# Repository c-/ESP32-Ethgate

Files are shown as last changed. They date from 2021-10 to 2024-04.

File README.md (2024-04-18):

# ESP32-Ethgate

This is an ESP32 (ESP32-WROOM-32 module) with LAN8720A PHY project
intended to be an ESP-NOW to (wired) MQTT gateway.

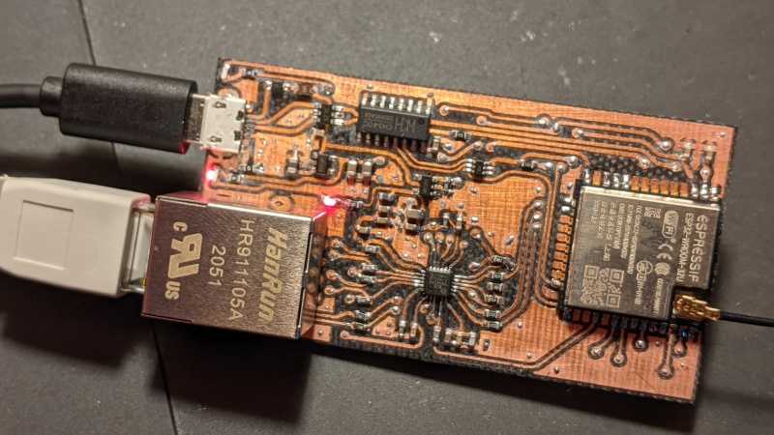
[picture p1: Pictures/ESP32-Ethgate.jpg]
Photo of working board


It was designed to be produced in my PCB mill. If your PCB mill can handle
QFN24 footprints and double-sided PCB's then you might be able to duplicate
this. Or you can just order a PCB from pretty much anywhere.
[I had a few made by Oshpark](https://oshpark.com/shared_projects/cBIYloft).

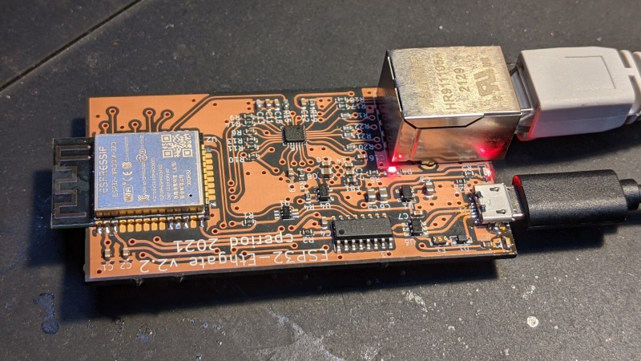
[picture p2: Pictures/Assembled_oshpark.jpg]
Oshpark After Dark PCB


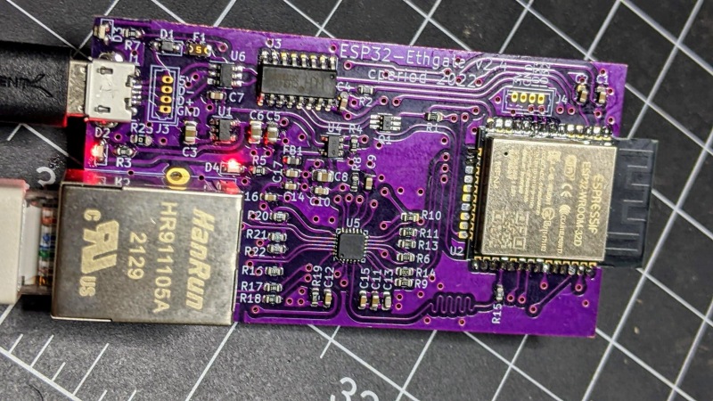
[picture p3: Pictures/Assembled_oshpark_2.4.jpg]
Oshpark After Dark PCB


# Design

For simplicity, it uses the GPIO17 PLL clock technique rather than
the GPIO0-based crystal, and includes a second 3.3v regulator to control
the entire ethernet power rail independently. It needs stable USB power,
although at some point I might take a stab at a PoE version.

The CH340C runs off the first regulator along with the ESP32. The HT7233 is
rated for 300mA, which is just marginal for an ESP32, but so far I haven't
noticed any power issues (power consumption for the whole board averages
maybe 250mA). I've thrown in some USB ESD protection, a fuse,
and some reverse protection (I know that's not supposed to be a problem
with USB... things happen, don't ask). ESD protection for the Ethernet
port would be a nice-to-have at some point.

The CH340C supports the usual auto-programming. Note that you *may* 
need to dial back the default upload baud rate.

I've added a small (1.25mm pitch) header with 3V3, GND, and two GPIO's
to allow for things like environmental sensors. Note that temperature
sensors will need to stay a minimum of 10cm off the board to avoid the heat
thrown by this board. I've also broken out the USB interface with a small
header (uUSB connectors can be brittle pieces of junk).

# BOM

Most of the components are from LCSC. There's an interactive BOM page
which should tell you what you need. Passives are 0603 with a few
0805 for the larger capacitors.

# Firmware

The Arduino-ESP32 ETH_LAN8720 sketch should work with the following
configuration:

```
#define LED_BUILTIN 2	// or use a NodeMCU-type of board definition
#define ETH_CLK_MODE    ETH_CLOCK_GPIO17_OUT
#define ETH_POWER_PIN   12
#define ETH_TYPE        ETH_PHY_LAN8720
#define ETH_ADDR        1
#define ETH_MDC_PIN     23
#define ETH_MDIO_PIN    18

ETH.begin(ETH_ADDR, ETH_POWER_PIN, ETH_MDC_PIN, ETH_MDIO_PIN,
	ETH_TYPE, ETH_CLK_MODE)
```

I flash mine with the ESP32 clock set at 80MHz, which seems to be
more stable at 100Mbps connection speeds and draws approximately 25%
less power.

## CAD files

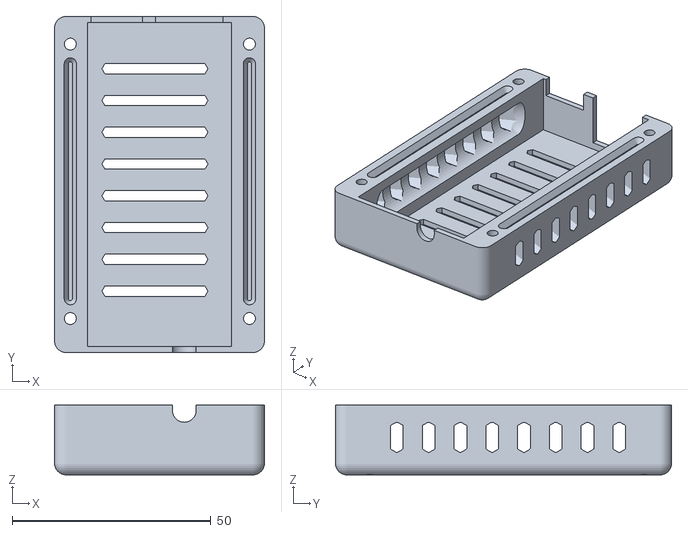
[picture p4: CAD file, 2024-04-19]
Models/Case - top.stl
52.9 x 84.7 x 17.6

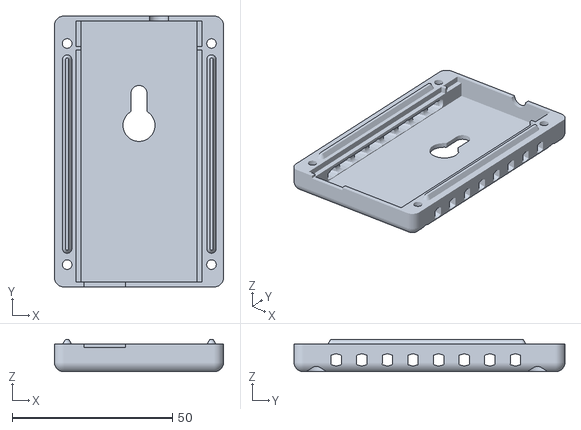
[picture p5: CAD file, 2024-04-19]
Models/Case - bottom.stl
52.9 x 84.7 x 10.1

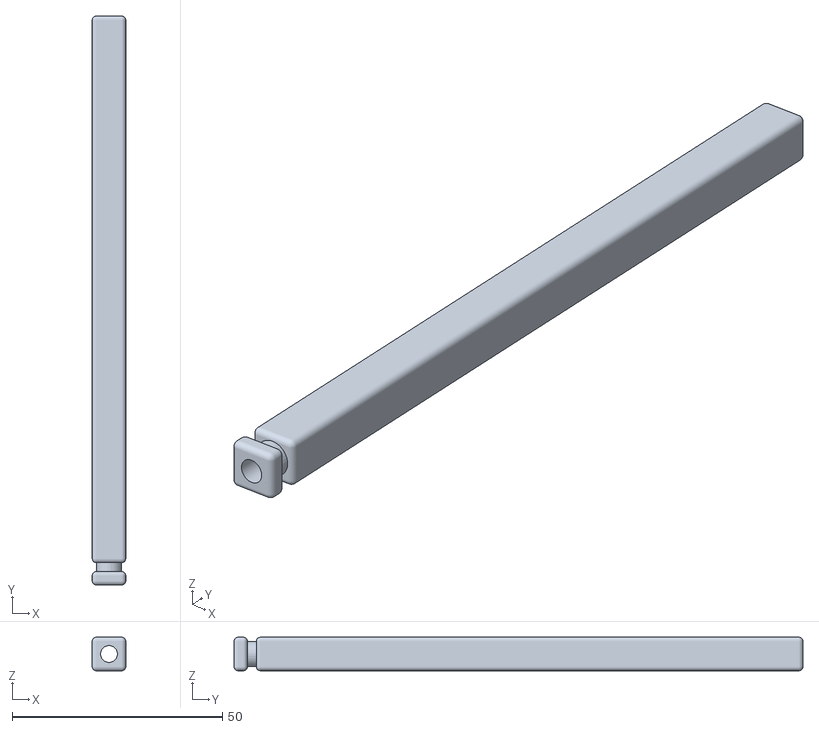
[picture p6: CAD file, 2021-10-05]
Models/Case - antenna.stl
7.99 x 135.3 x 7.99

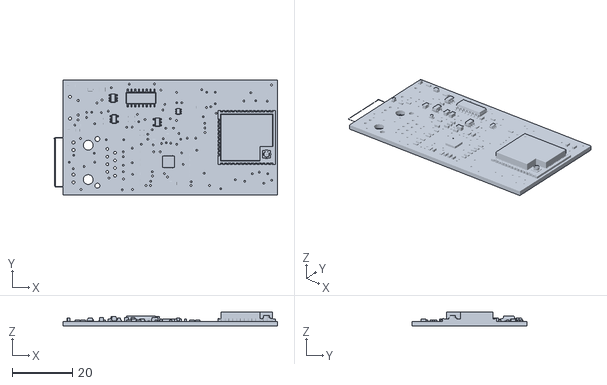
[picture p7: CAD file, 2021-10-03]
Models/ESP32-Ethgate.stl
74.1 x 38.1 x 4.81

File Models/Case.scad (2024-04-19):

part = "all";	// [bottom, top, antenna]

screwd = 3;
screwheadd = 7;
w = 1.6;
pcbx = 39.5;
x = pcbx + screwheadd + w*2;
ay = 9;
y = 72.5 + ay;	// incl antenna
z = 23;
bz = 6;	// bottom height
pcbt = 2;
antennaod = 8;
antennaid = 4;	// ipex connector size
antennacd = 6;	// connecting hole
antennal = 130;
ventd = 3;
$fn=36;

screws = [
	[w*1.5,screwheadd-w],
	[w*.5+x-screwd, screwheadd-w],
	[w*1.5,y-screwheadd],
	[w*.5+x-screwd, y-screwheadd],
];

module sylinder( r, h ) {
   hull() {
      translate([0,0,r]) sphere(r=r);
      translate([0,0,h-r]) sphere(r=r);
   }
}

module scube( v, r=2 ) {
   hull() {
      translate([r,r,0]) sylinder(r=r,h=v[2]);
      translate([v[0]-r,r,0]) sylinder(r=r,h=v[2]);
      translate([r,v[1]-r,0]) sylinder(r=r,h=v[2]);
      translate([v[0]-r,v[1]-r,0]) sylinder(r=r,h=v[2]);
   }
}

module antenna(solid=0) {
	difference() {
		union() {
			translate([-antennaod/2,-antennaod/2,w*3+0.5])
				scube([antennaod,antennaod,antennal],1);
			cylinder(d=antennaod,h=w*3+1);
			*translate([-antennaod/2,-antennaod/2,0])
				scube([antennaod,antennaod,w*2],1);
		}
		if( !solid ) {
			cylinder(d=antennaid,h=antennal+w*4);
			translate([0,0,w*5]) cylinder(d=antennacd,h=antennal);
		}
	}
}

module screw(hd=screwheadd,sd=screwd,taper=0,clear=0) {
	s = (taper && hd && sd) ? (hd-sd)/2 : 0;
	cylinder(d=sd,h=z*2);
	if( s ) {
		translate([0,0,bz-s]) cylinder(d2=sd,d1=hd,h=s);
	}
	translate([0,0,-s]) cylinder(d=hd,h=bz);
	
	// extra clearance for the first bit
	if( clear ) {
		cylinder(d=sd+1, h=bz+clear);
	}
}

module vent() {
	hull() {
		rotate([0,90,0]) cylinder(d=ventd,h=x+w*4,$fn=6);
		translate([0,0,z/5]) rotate([0,90,0])
			cylinder(d=ventd,h=x+w*4,$fn=6);
		translate([(x+w*3)/2,0,0])  rotate([0,90,0])
			scale([1,5,1]) cylinder(d=ventd,h=w,$fn=6);
	}
}

module vertvent() {
	hull() {
		cylinder(d=ventd,h=z,$fn=6);
		translate([pcbx*.6,0,0]) cylinder(d=ventd,h=z,$fn=6);
	}
}

module vent_relief(yoff,h=z/2) {
	rotate([-90,0,0])
		scale([1.5,1.7,1]) sylinder(r=h/4, h=y-yoff*2);
}

module body() {
	difference() {
		translate([-w,-w,-bz-w]) scube([x+w*2, y+w*2, z+w*2],3);

		// these are PCB-relative
		translate([(x-pcbx)/2,0,0]) union() {
			
			// main cavity
			translate([w,0,-bz]) cube([pcbx-w*2, y, z]);

			// pcb itself, with a small stop tab
			translate([0,0,-pcbt/2]) difference() {
				cube([pcbx, y, pcbt]);
				translate([0,y-ay,0]) cube([pcbx, 1, pcbt]);
			}
			
			// ethernet cutout
			translate([18.7,-w-0.1,pcbt/2]) cube([17, w*2, 14]);
			
			// usb cutout
			translate([2.5,-w-0.1,0]) cube([13,w*5,6]);
			
			// antenna cutout
			translate([0,y-w,-antennaod/3]) hull() {
				translate([26,0,antennaod/2+pcbt/2])
					rotate([-90,0,0])
						cylinder(d=antennacd,h=antennal);
				translate([26,0,antennacd/2+pcbt/2])
					rotate([-90,0,0])
						cylinder(d=antennacd,h=antennal);
			}
		}
		
		// keyhole mount in bottom
		translate([x/2,y*0.6,-bz-w]) {
			cylinder(d=10,h=w*2);
			hull() {
				cylinder(d=5,h=w*2);
				translate([0,10,0]) cylinder(d=5,h=w*2);
			}
		}
		
		// screw holes
		for( v = screws ) {
			translate([v[0],v[1],-bz-pcbt]) screw(taper=1,clear=w+pcbt/2);
		}

		// vents
		for( yy=[(screwheadd+ventd+w):8:y-(screwheadd+ventd+w)] ) {
			translate([-w*2,yy,-bz/2-2]) scale([1,1,0.5]) vent();
			translate([-w*2,yy,(z-bz)/2-w]) vent();
			translate([pcbx*.3,yy,0]) vertvent();
		}
		
		// relieve around the vents... more airflow, less material
		byoff = 10;
		tyoff = 8;
		v = w+3+ventd;
		translate([(x-pcbx+w*2)/2,tyoff,pcbt/2+v]) vent_relief(tyoff);
		translate([x-(x-pcbx)/2-w,tyoff,pcbt/2+v]) vent_relief(tyoff);

		translate([(x-pcbx+w*2)/2,byoff,-z/2+v]) vent_relief(byoff,bz-2);
		translate([x-(x-pcbx)/2-w,byoff,-z/2+v]) vent_relief(byoff,bz-2);
	}
}

module alignment(s=1) {
	translate([0,0,pcbt/2]) union() {
		hull() {
			translate([screws[0][0],screws[0][1]+5,0])
				scale([s,s,s]) cylinder(d1=screwd,d2=screwd/3,h=w);
			translate([screws[2][0],screws[2][1]-5,0])
				scale([s,s,s]) cylinder(d1=screwd,d2=screwd/3,h=w);
		}
		hull() {
			translate([screws[1][0],screws[1][1]+5,0])
				scale([s,s,s]) cylinder(d1=screwd,d2=screwd/3,h=w);
			translate([screws[3][0],screws[3][1]-5,0])
				scale([s,s,s]) cylinder(d1=screwd,d2=screwd/3,h=w);
		}
	}
}

module top() {
	intersection() {
		body();
		difference() {
			translate([-x/2,-y/2,pcbt/2]) cube([x*2,y*2,z]);
			
			// want the alignment hollows to be slightly oversized
			alignment(1.03);
		}
	}
}

module bottom() {
	intersection() {
		body();
		union() {
			translate([-x/2,-y/2,pcbt/2-z]) cube([x*2,y*2,z]);
			alignment(0.97);
		}
	}
}

if( part == "all" ) {
	translate([pcbx,0,0]) rotate([0,0,90]) color("green")
		import("ESP32-Ethgate.stl");

	color("grey") translate([26+antennaod/2-(x-pcbx)/2,y-w*2,pcbt+1])
					rotate([-90,0,0]) antenna();

	translate([-(x-pcbx)/2,0,w]) top();
	translate([-(x-pcbx)/2,0,0]) bottom();
} else if( part == "antenna" ) {
	rotate([-90,0,0]) antenna();
} else if( part == "top" ) {
	rotate([-180,0,0]) top();
} else if( part == "bottom" ) {
	bottom();
}

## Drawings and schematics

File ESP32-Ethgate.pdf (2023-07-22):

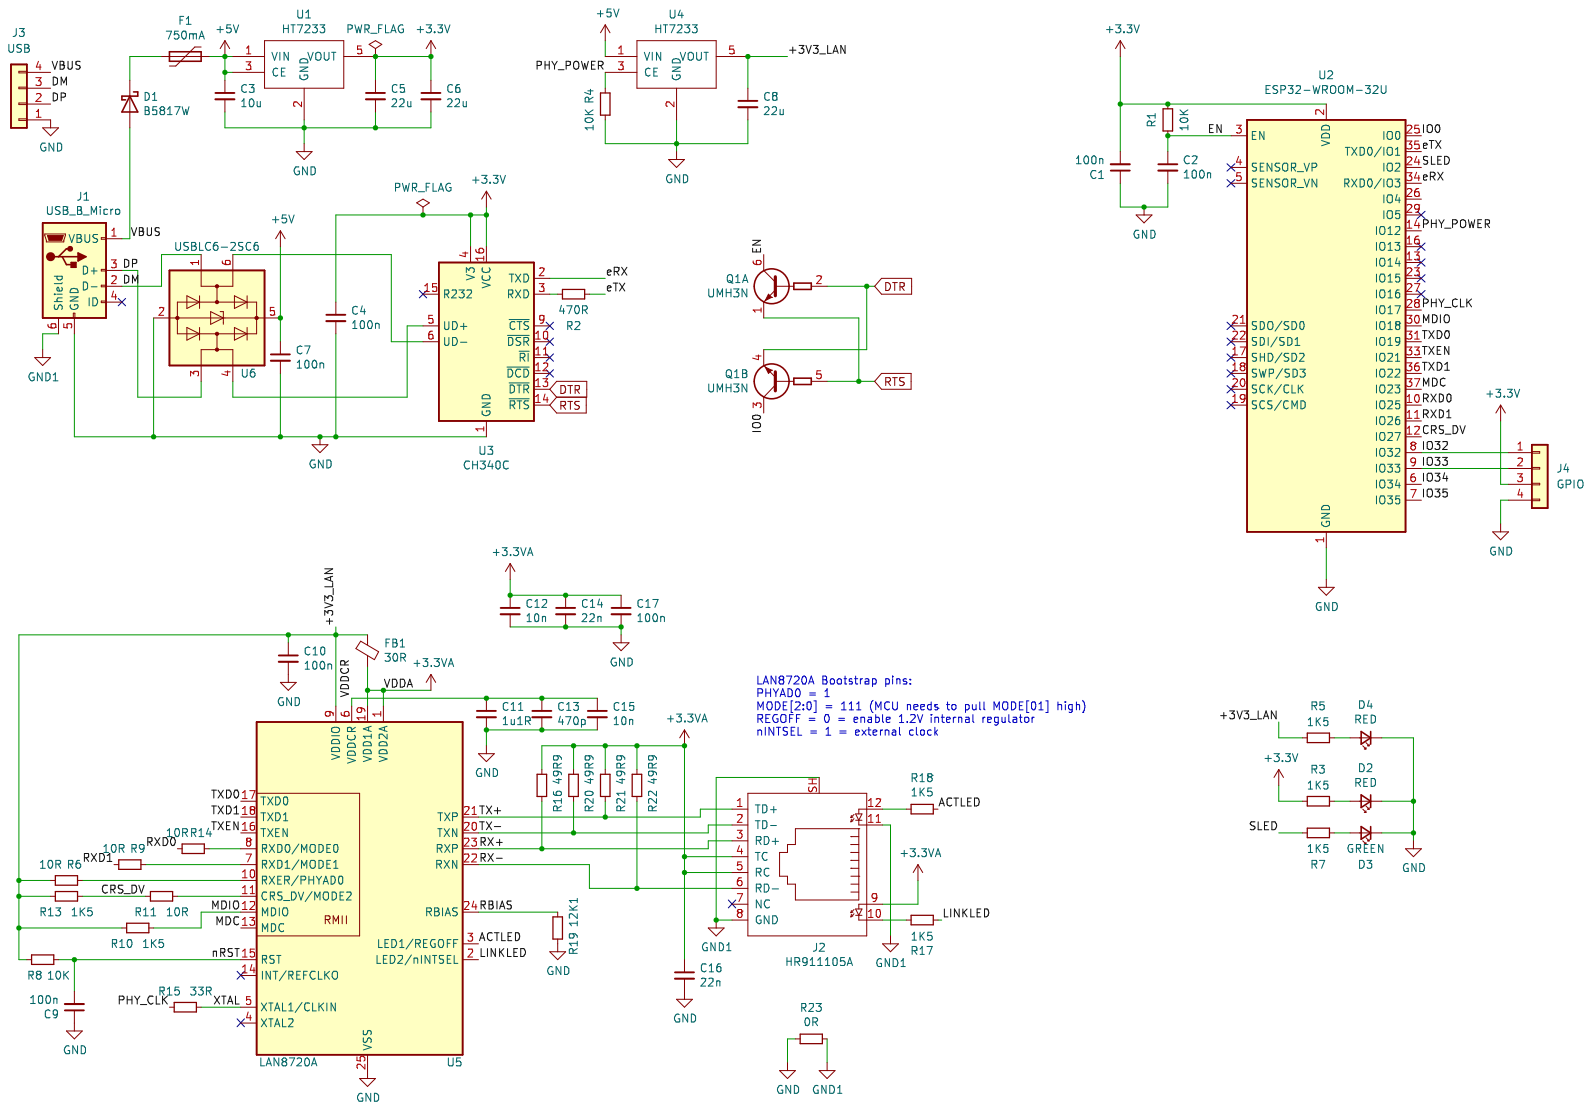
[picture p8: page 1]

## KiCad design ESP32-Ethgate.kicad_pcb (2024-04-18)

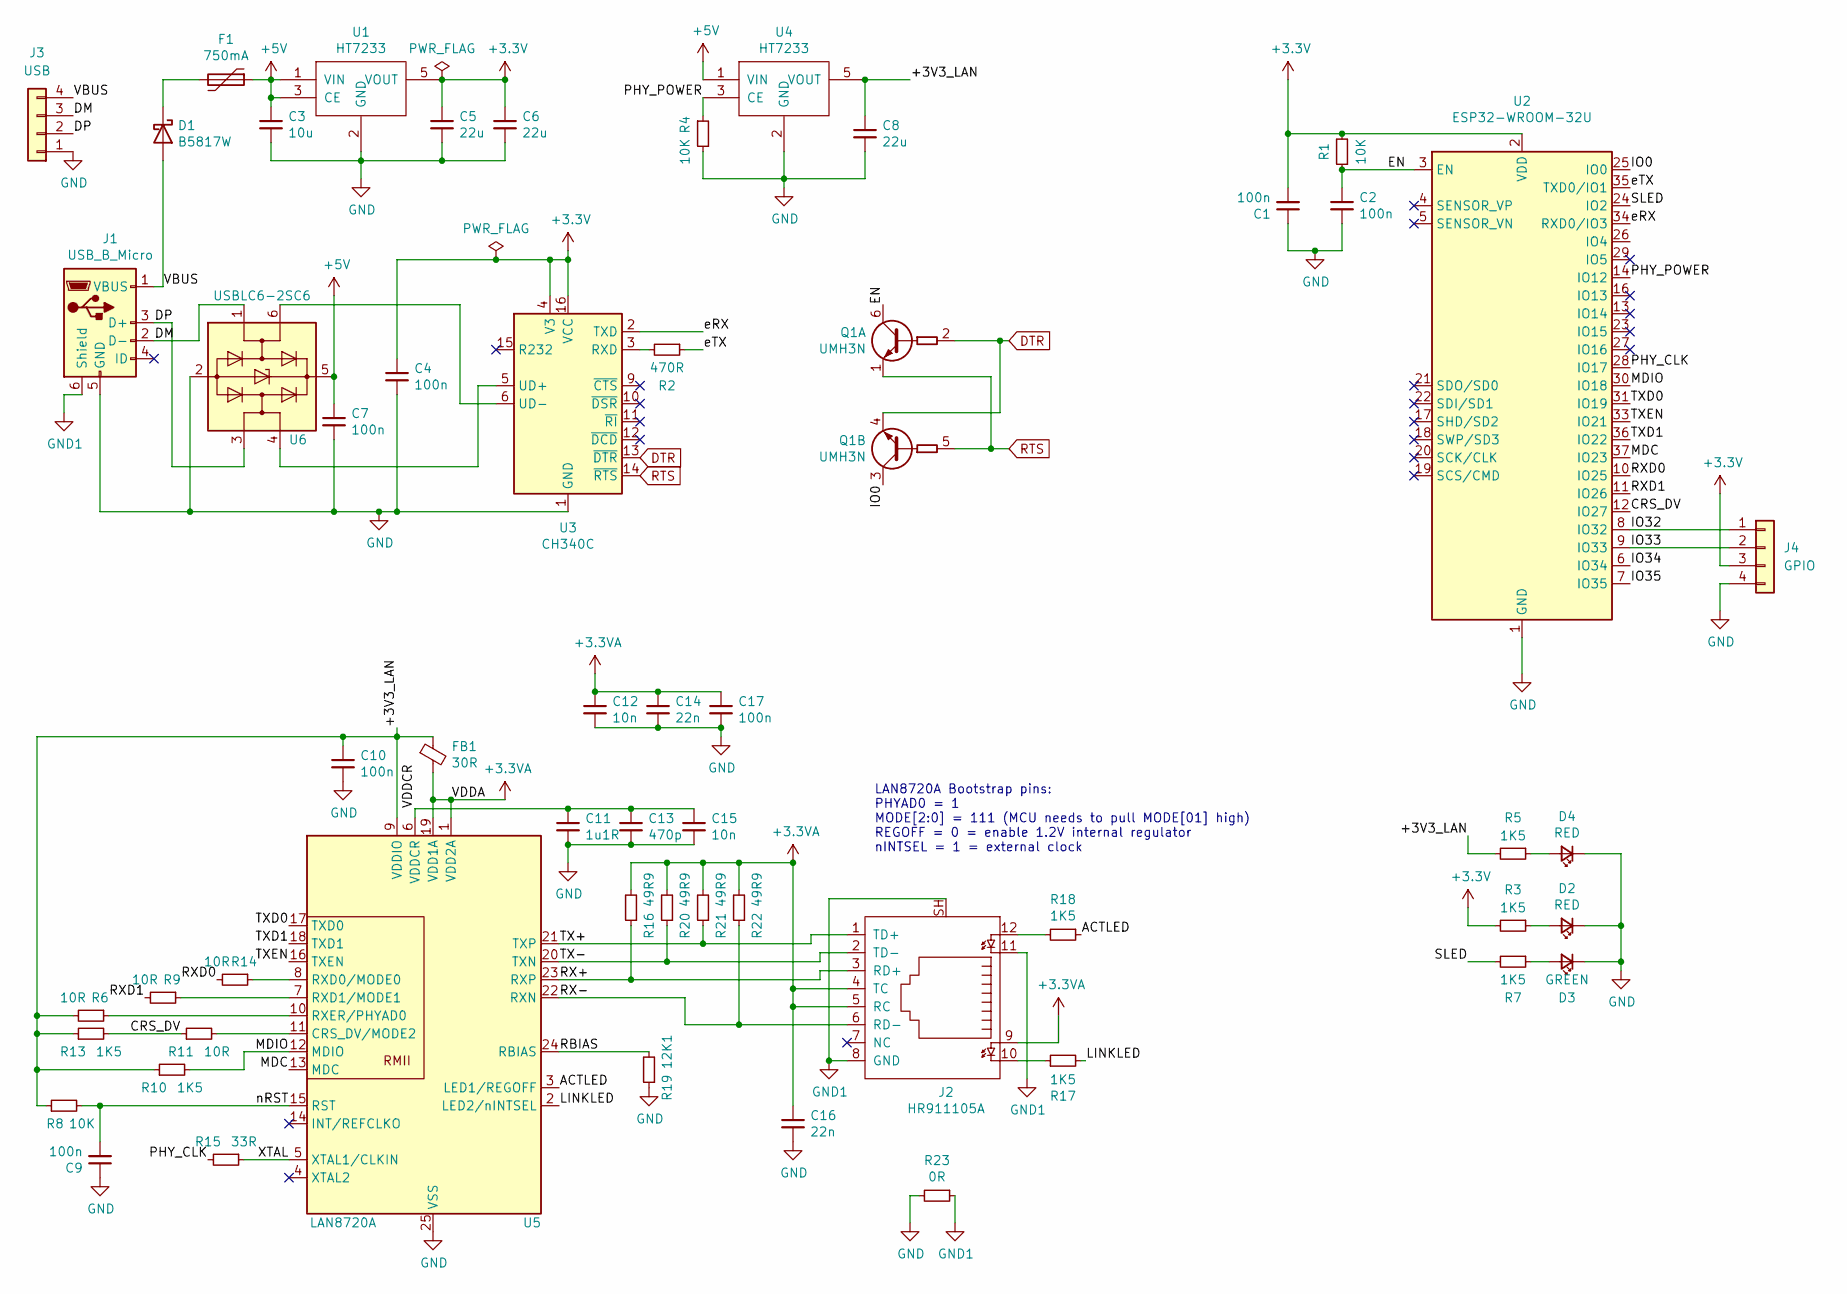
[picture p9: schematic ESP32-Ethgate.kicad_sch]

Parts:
C1, C2, C4, C7, C9, C10, C17: 100n; C_0603_1608Metric
C3: 10u; C_0805_2012Metric
C5, C6, C8: 22u; C_0805_2012Metric
C11: 1u1R; C_0603_1608Metric
C12, C15: 10n; C_0603_1608Metric
C13: 470p; C_0603_1608Metric
C14, C16: 22n; C_0603_1608Metric
D1: B5817W; D_SOD-323_HandSoldering
D2, D4: RED; LED_0603_1608Metric_Castellated
D3: GREEN; LED_0603_1608Metric_Castellated
F1: 750mA; Fuse_0805_2012Metric_Pad1.15x1.40mm_HandSolder
FB1: 30R; L_0603_1608Metric
J1: USB_B_Micro; USB_Micro-B_CNC_C10418
J2: HR911105A; RJ45_Hanrun_HR911105A_Oval
J3: USB; Molex_PicoBlade_53047-0410_1x04_P1.25mm_Vertical
J4: GPIO; Molex_PicoBlade_53047-0410_1x04_P1.25mm_Vertical
Q1: UMH3N; SOT-363_SC-70-6_Handsoldering
R1, R4, R8: 10K; R_0603_1608Metric
R2: 470R; R_0603_1608Metric
R3, R5, R7, R10, R13, R17, R18: 1K5; R_0603_1608Metric
R6, R9, R11, R14: 10R; R_0603_1608Metric
R15: 33R; R_0603_1608Metric
R16, R20, R21, R22: 49R9; R_0603_1608Metric
R19: 12K1; R_0603_1608Metric
R23: 0R; R_0603_1608Metric
U1, U4: HT7233; SOT-23-5
U2: ESP32-WROOM-32U; ESP32-WROOM-32U-HandSoldering
U3: CH340C; SOIC-16_3.9x9.9mm_P1.27mm
U5: LAN8720A; QFN-24-1EP_4x4mm_P0.5mm_EP2.6x2.6mm
U6: USBLC6-2SC6; SOT-23-6_Handsoldering

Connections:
+3.3VA: C12.1, C14.1, C16.1, C17.1, FB1.2, J2.4 (TC), J2.5 (RC), J2.9, R16.2, R20.2, R21.2, R22.2, U5.1 (VDD2A), U5.19 (VDD1A)
+3V3: C1.2, C4.1, C5.1, C6.1, J4.3, R1.2, R3.2, U1.5 (VOUT), U2.2 (VDD), U3.4 (V3), U3.16 (VCC)
+5V: C3.1, C7.1, F1.1, U1.1 (VIN), U1.3 (CE), U4.1 (VIN), U6.5 (VBUS)
/+3V3_LAN: C8.1, C10.1, FB1.1, R5.2, R6.2, R8.1, R10.1, R13.1, U4.5 (VOUT), U5.9 (VDDIO)
/ACTLED: R18.1, U5.3 (LED1/REGOFF)
/CRS_DV: R11.1, R13.2, U2.12 (IO27)
/DM: J1.2 (D-), J3.3, U6.1 (I/O1)
/DP: J1.3 (D+), J3.2, U6.3 (I/O2)
/EN: C2.1, Q1.6 (C1), R1.1, U2.3 (EN)
/IO0: Q1.3 (C2), U2.25 (IO0)
/IO32: J4.1, U2.8 (IO32)
/IO33: J4.2, U2.9 (IO33)
/IO34: U2.6 (IO34)
/IO35: U2.7 (IO35)
/LINKLED: R17.2, U5.2 (LED2/nINTSEL)
/MDC: U2.37 (IO23), U5.13 (MDC)
/MDIO: R10.2, U2.30 (IO18), U5.12 (MDIO)
/PHY_CLK: R15.2, U2.28 (IO17)
/PHY_POWER: R4.1, U2.14 (IO12), U4.3 (CE)
/RBIAS: R19.2, U5.24 (RBIAS)
/RX+: J2.3 (RD+), R16.1, U5.23 (RXP)
/RX-: J2.6 (RD-), R22.1, U5.22 (RXN)
/RXD0: R14.2, U2.10 (IO25)
/RXD1: R9.2, U2.11 (IO26)
/SLED: R7.2, U2.24 (IO2)
/TX+: J2.1 (TD+), R21.1, U5.21 (TXP)
/TX-: J2.2 (TD-), R20.1, U5.20 (TXN)
/TXD0: U2.31 (IO19), U5.17 (TXD0)
/TXD1: U2.36 (IO22), U5.18 (TXD1)
/TXEN: U2.33 (IO21), U5.16 (TXEN)
/VBUS: D1.2 (A), J1.1 (VBUS), J3.4
/VDDCR: C11.1, C13.1, C15.1, U5.6 (VDDCR)
/XTAL: R15.1, U5.5 (XTAL1/CLKIN)
/eRX: U2.34 (RXD0/IO3), U3.2 (TXD)
/eTX: R2.1, U2.35 (TXD0/IO1)
/nRST: C9.2, R8.2, U5.15 (RST)
DTR: Q1.2 (B1), Q1.4 (E2), U3.13 (~DTR)
GND: C1.1, C2.2, C3.2, C4.2, C5.2, C6.2, C7.2, C8.2, C9.1, C10.2, C11.2, C12.2, C13.2, C14.2, C15.2, C16.2, C17.2, D2.1 (K), D3.1 (K), D4.1 (K), J1.5 (GND), J3.1, J4.4, R4.2, R19.1, R23.2, U1.2 (GND), U2.1 (GND), U2.15 (GND), U2.38 (GND), U2.39 (GND), U3.1 (GND), U4.2 (GND), U5.25 (VSS), U6.2 (GND)
GND1: J1.6 (Shield), J2.8 (GND), J2.11, J2.SH, R23.1
unnamed: D1.1 (K), F1.2
unnamed: D2.2 (A), R3.1
unnamed: D3.2 (A), R7.1
unnamed: D4.2 (A), R5.1
unnamed: J2.10, R17.1
unnamed: J2.12, R18.2
unnamed: R2.2, U3.3 (RXD)
unnamed: U3.5 (UD+), U6.4 (I/O2)
unnamed: U3.6 (UD-), U6.6 (I/O1)
unnamed: R11.2, U5.11 (CRS_DV/MODE2)
unnamed: R14.1, U5.8 (RXD0/MODE0)
unnamed: R9.1, U5.7 (RXD1/MODE1)
unnamed: R6.1, U5.10 (RXER/PHYAD0)
RTS: Q1.1 (E1), Q1.5 (B2), U3.14 (~RTS)

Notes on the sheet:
LAN8720A Bootstrap pins: PHYAD0 = 1 MODE[2:0] = 111 (MCU needs to pull MODE[01] high) REGOFF = 0 = enable 1.2V internal regulator nINTSEL = 1 = external clock

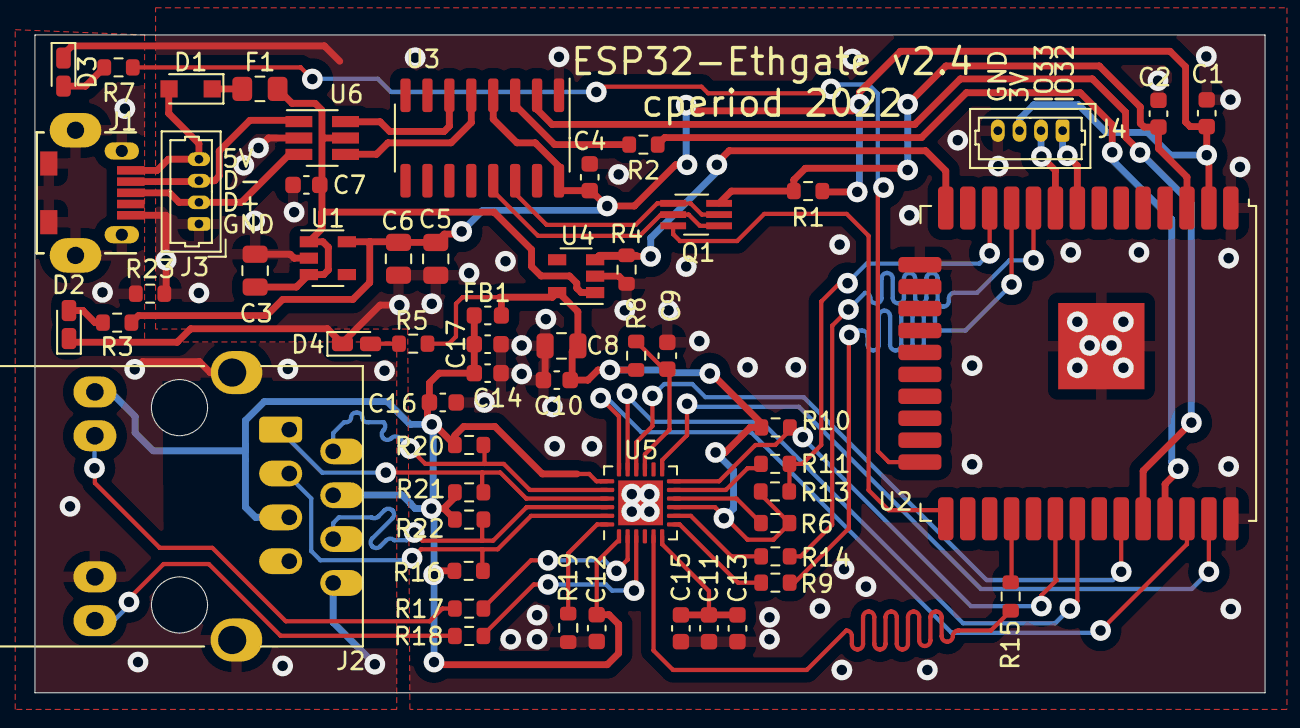
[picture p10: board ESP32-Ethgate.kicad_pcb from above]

Board: 2 copper layers, 71.2 x 38.1 mm, 56 parts (0 on the bottom side), 51 nets.

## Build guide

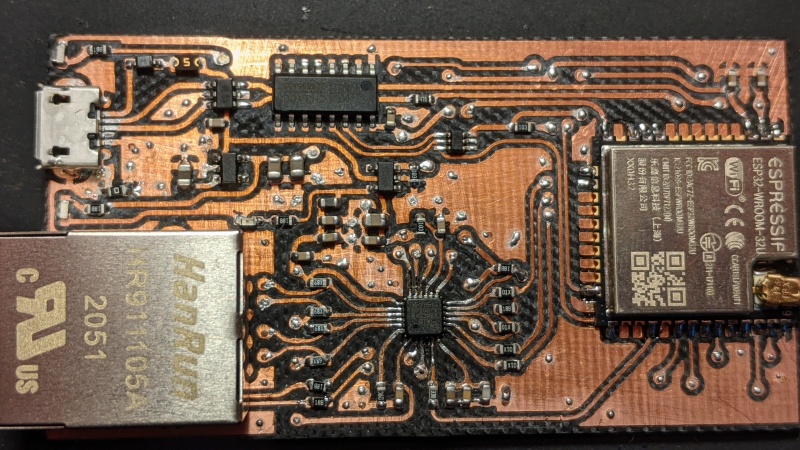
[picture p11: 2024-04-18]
Pictures/Assembled_Front.jpg

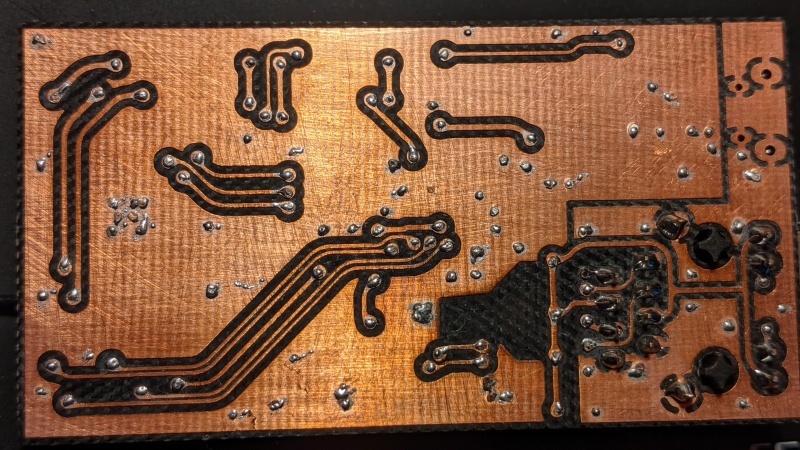
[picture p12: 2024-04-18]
Pictures/Assembled_Back.jpg

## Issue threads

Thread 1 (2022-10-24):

Internal REG on or off?

zubeer95, 2022-10-24:
Hi,
thanks for sharing this project.
I was checking it and there is someting that seems to be a bit off, could you please help me to understand what I am missing?

I can see from the schematic that VDDCR is left floating, thus I assume that you are using the internal regular of LAN8720A, however, the pin LED1/REGOFF is pulled up at VDD2A.
From the datasheet, http://ww1.microchip.com/downloads/en/DeviceDoc/8720a.pdf section 3.7.3.1 it states:"To disable the +1.2V internal regulator, a pull-up strapping resistor should be connected from the REGOFF configuration strap to VDD2A".

So it is not clear if the internal regular is on or off in your solution, I believe that the correct design for that led should be as it is in section 3.8.1.1;

Let me know what I am missing.

Kind regards
Z.

c-, 2022-10-31:
I think you're right. I cribbed that part of my schematic from another source without looking too deeply at the details.

Best theory as to why it still works (I have a bunch running, so it definitely works) is that 1.5K current limiting resistor on the LED. The datasheet and schematic checklist recommend something more like 300R, and there's a note in the schematic checklist about "Due to possible lower I/O voltages used on the LAN8720, lower strapping resistor values need to be used to ensure the strapped configuration is properly latched", so that 1.5K in tandem with the LED forward voltage drop (~1.8V for the LED's in that connector), the built-in pulldown might be enough to tip the balance towards "LOW" during power-on.

Well, I'll fix that. I was planning on doing an update soonish.

zubeer95, 2022-11-25:
Great, I saw the same mistake in other projects online and some open-source mass-produced products.
Better to update if to avoid further propagation of this error!

c-, 2022-11-28:
I've pushed an updated version which should fix this problem, among other things. Untested at the moment. I'm firing off an oshpark order as my PCB mill is currently undergoing a controller cleanup.

c-, 2023-07-18:
You're absolutely right, and I never even had a chance to assemble that last batch of boards. What you've described is how the Olimex ESP32-PoE board does it (with a LAN8710). I guess I need another spin...

mihaipenica, 2023-08-28:
Hi , thank you for sharing this. Is there any chance you can also upload a version of your working code.
My board is requesting dhcp IP from the router. The router offers the IP, but the device is not setting it. I have checked everything and am trying to figure out what might be the problem.
Thank you!

Gi-z, 2023-12-06:
+1, also having this same issue. Tested with both esp-idf and Arduino IDE's LAN_8720 example.

c-, 2024-04-18:
I *finally* got around to bringing up a fixed (v2.4) board, and it seems quite happy now.

Closed 2024-04-18.

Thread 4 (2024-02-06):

Working example of MQTT over LAN

biswajitkgp, 2024-02-06:
First of all, congratulations on this amazing project, and thank you so much for sharing it online. You mentioned that you intended to use this as an ESP-NOW to (wired) MQTT gateway. Could you please share a working example code for MQTT?? It will be really helpful. Thanks in advance.

c-, 2024-02-06:
Unfortunately, I had a bit of an accident the other day and wiped the firmware. Apparently I never got around to adding it to a git repo.

So now I need to rewrite it (or reconstitute it from my W5500 version).

biswajitkgp, 2024-02-07:
Oh I'm so sorry to hear that. However, if you decide to reconstitute it, please upload it to GitHub this time. Thanks

c-, 2024-04-18:
I've uploaded some very rough and ready firmware. It's not pretty, but it does actually work as an ESP-NOW-to-MQTT relay via the LAN.

Note that my ESP-NOW sensors basically transmit MQTT-ready chunks of data, so my relay code is tuned for that. YMMV.

Closed 2024-04-18.

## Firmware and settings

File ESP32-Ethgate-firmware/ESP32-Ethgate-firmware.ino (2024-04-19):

#include <Arduino.h>
#include <WiFi.h>
extern "C" {
  #include <esp_now.h>
  #include <esp_wifi.h>
}
#include <ESPmDNS.h>
#include <ArduinoOTA.h>

#include <MQTT.h>
#include <Ticker.h>

#include <ETH.h>

// network specific definitions
#include "Private.h"
#ifndef PRIVATE_H
#define WIFI_CHANNEL    7
#define MQTT_SERVER "192.168.1.1"
#define MQTT_USER "test"
#define MQTT_PASS "pass"
#define OTA_PASSWORD "pass"
#endif

#define LED_BUILTIN 2	// or use a NodeMCU-type of board definition
#define ETH_CLK_MODE    ETH_CLOCK_GPIO17_OUT
#define ETH_POWER_PIN   12
#define ETH_TYPE        ETH_PHY_LAN8720
#define ETH_ADDR        1
#define ETH_MDC_PIN     23
#define ETH_MDIO_PIN    18

static WiFiClient ethClient;
static MQTTClient client(512);
static Ticker updater;
static String nodeid("ethgate-");

static bool eth_connected = false;
static long lastrelayed = 0;
static long relayed = 0;

static inline void led_on() {
  digitalWrite(LED_BUILTIN, HIGH);
}
static inline void led_off() {
  digitalWrite(LED_BUILTIN, LOW);
}

static void espnow_recv(const unsigned char* mac,
  const unsigned char* data, int len
) {
    char* msg = strchr((char*)data,' ');
    if( msg == NULL ) return;
    *msg = 0;
    msg ++;
  
    led_on();

    // FIXME: we should be putting this in a queue, not sending
    // in the receive callback.
    client.publish((char*)data, msg);
    client.loop();
  
    Serial.print((char*)data);
    Serial.print(" ");
    Serial.println(msg);

    lastrelayed = millis();
    relayed ++;

    led_off();
}

static void initEspNow() {
  Serial.println("Starting ESPNOW");

  wifi_init_config_t cfg = WIFI_INIT_CONFIG_DEFAULT();
  esp_wifi_init(&cfg);
  esp_wifi_set_mode(WIFI_MODE_STA);
  esp_wifi_start();
  esp_wifi_set_promiscuous(true);
  esp_wifi_set_channel(WIFI_CHANNEL, WIFI_SECOND_CHAN_NONE);
  
  if (esp_now_init()!=0) {
    Serial.println("*** ESP_Now init failed");
    ESP.restart();
  }

  esp_now_register_recv_cb(espnow_recv);
}

void updateMessage() {
  if( !eth_connected ) return;

  char msg[256];

  snprintf(msg,sizeof(msg),
    "{\"relayed\":%d,\"idle\":%d,\"ip\":\"%s\"}",
    relayed, (millis()-lastrelayed)/1000,
    ETH.localIP().toString().c_str() );

  String topic = "sensors/";
  topic += nodeid;
  topic += "/status";

  client.publish(topic, msg);
  client.loop();

  Serial.print(topic);
  Serial.print(" ");
  Serial.println(msg);
}

void WiFiEvent(WiFiEvent_t event)
{
  switch (event) {
    case ARDUINO_EVENT_ETH_START:
      Serial.println("ETH Started");
      //set eth hostname here
      ETH.setHostname(nodeid.c_str());
      break;
    case ARDUINO_EVENT_ETH_CONNECTED:
      Serial.println("ETH Connected");
      break;
    case ARDUINO_EVENT_ETH_GOT_IP:
      Serial.print("ETH MAC: ");
      Serial.print(ETH.macAddress());
      Serial.print(", IPv4: ");
      Serial.print(ETH.localIP());
      if (ETH.fullDuplex()) {
        Serial.print(", FULL_DUPLEX");
      }
      Serial.print(", ");
      Serial.print(ETH.linkSpeed());
      Serial.println("Mbps");
      eth_connected = true;

      ArduinoOTA.begin();
      break;
    case ARDUINO_EVENT_ETH_DISCONNECTED:
      Serial.println("ETH Disconnected");
      eth_connected = false;
      break;
    case ARDUINO_EVENT_ETH_STOP:
      Serial.println("ETH Stopped");
      eth_connected = false;
      break;
    default:
      break;
  }
}

void setup()
{
  pinMode(LED_BUILTIN,OUTPUT);

  {
    char buf[16];
    nodeid += itoa((ESP.getEfuseMac()&0xffffff000000)>>24,buf,16);
  }

  Serial.begin(115200);

  Serial.println(nodeid);

  initEspNow();

  WiFi.onEvent(WiFiEvent);
  ETH.begin(ETH_ADDR, ETH_POWER_PIN, ETH_MDC_PIN, ETH_MDIO_PIN,
	  ETH_TYPE, ETH_CLK_MODE);

  client.begin(MQTT_SERVER, 1883, ethClient);
  client.loop();

  ArduinoOTA.setHostname(nodeid.c_str());
  ArduinoOTA.setPassword(OTA_PASSWORD);
  
  MDNS.begin(nodeid.c_str());

  updater.attach(60, updateMessage);
}

static long last_connect = 0;

void loop() {
  if( !client.connected() && millis()-last_connect>5000 ) {
    Serial.println("(Re)connecting to MQTT");
    client.connect(nodeid.c_str(),MQTT_USER,MQTT_PASS);
    last_connect = millis();
  }

  ArduinoOTA.handle();
  client.loop();

  delay(1);
}

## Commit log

2021-03-07 first stab based on W5500. Going to try something else.
    [ESP32-Ethgate.kicad_pcb, ESP32-Ethgate.sch]
2021-03-14 finished layout
    [ESP32-Ethgate.kicad_pcb, ESP32-Ethgate.sch]
2021-04-02 add USB ESD, generate rounded tracks version
    [ESP32-Ethgate.kicad_pcb, ESP32-Ethgate.sch]
2021-05-11 more tweaks
    [ESP32-Ethgate.kicad_pcb, ESP32-Ethgate.sch]
2021-07-10 better, but still not working.
    [ESP32-Ethgate.kicad_pcb, ESP32-Ethgate.sch]
2021-07-12 Working schematic, with proper ethernet connector pinouts
    [ESP32-Ethgate.sch]
2021-07-12 some layout tweaks to clean things up and make assembly a hair easier
    [ESP32-Ethgate.kicad_pcb]
2021-07-12 chop the ground plane up a bit less
    [ESP32-Ethgate.kicad_pcb]
2021-07-17 more layout tweaks
    [ESP32-Ethgate.kicad_pcb]
2021-07-19 more tuning
    [ESP32-Ethgate.kicad_pcb]
2021-07-20 add some documentation
    [ESP32-Ethgate.sch]
2021-10-03 add a case
    [Case - antenna.stl, Case - bottom.stl, Case - top.stl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]
2021-10-05 more case tweaks
    [Case - antenna.stl, Case - bottom.stl, Case - top.stl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]
2021-11-15 PDF schematic
    [ESP32-Ethgate.kicad_pcb]
2022-11-01 update Kicad
    make sure REGOFF is properly pulled low, fixing #1
    add some 1.25mm pitch connectors for USB and a couple of GPIO's
    Assorted tweaks to some routing to ensure RMII signals and the clock are
    somewhat length matched.
    Extend the ground exclusion zone to past where the eth magnetics should
    be found.
    [ESP32-Ethgate.kicad_pcb, ESP32-Ethgate.kicad_sch]
2022-11-28 update the various extra files
    [ESP32-Ethgate.kicad_pcb, ESP32-Ethgate.kicad_sch]
2022-11-28 label the USB connections
    [ESP32-Ethgate-rounded.kicad_pcb, ESP32-Ethgate.kicad_pcb]
2022-11-28 update schematic PDF
2023-07-22 properly fix the nINTSEL for #1 (and document the bootstrap settings in the schematic so I remember next time).
    this implicitly updates to Kicad 7.
    [ESP32-Ethgate-rounded.kicad_pcb, ESP32-Ethgate.kicad_pcb, ESP32-Ethgate.kicad_sch]
2023-07-22 update rev number
    [ESP32-Ethgate-rounded.kicad_pcb, ESP32-Ethgate.kicad_pcb]
2023-07-22 fix some silk designators
    [ESP32-Ethgate-rounded.kicad_pcb, ESP32-Ethgate.kicad_pcb]
2024-04-18 nothing big
    [Case.scad]
2024-04-18 small tweaks
    [ESP32-Ethgate-rounded.kicad_pcb, ESP32-Ethgate.kicad_pcb]
2024-04-18 swapped the GND/3V labels
    [ESP32-Ethgate-rounded.kicad_pcb, ESP32-Ethgate.kicad_pcb]
2024-04-18 a few small fixes
    [ESP32-Ethgate-firmware.ino]
2024-04-18 add a photo of the v2.4 board, and shrink the images down to something reasonable
2024-04-19 just a hair longer/wider to make room
    [Case - bottom.stl, Case - top.stl, Case.scad]
